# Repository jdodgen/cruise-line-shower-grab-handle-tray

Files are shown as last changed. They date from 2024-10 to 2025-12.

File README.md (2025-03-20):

# Shower grab handle tray
This is a [openSCAD](https://openscad.org/) design to create an accessory that attaches to the grab handle in the cruise ship shower.

The tray stores things normally on the floor and it also has a loop to hang a razor.   
There are scad "lists" for mount and tray versions. 

All/most variables are global and should be easy to customize. 

There are two scad files one for generating [tray](src/universal_tray.scad)s the other for the [mount](src/universal_mounts.scad) part. 
They are interconnected with a shared [dovetail](src/dovetail.scad). 

### current mount stl files
#### [20mm](/src/stl/20mm_mount.stl) grab handle
As found on Grand Princess and Discovery Princess   
I expect it is a pretty standard grab handle.
####  [25x50mm](/src/stl/25mm_mount.stl) shower handle pole 
As found on Discovery Princess 
#### [25mm](/src/stl/25mm_mount.stl) grab handle
not found on cruise ships yet but sort of standard.
#### [32.5mm](/src/stl/32mm_mount.stl) curved shower handle pole
as found on Discovery Princess wheelchair cabins
#### easy to customize
and add other mounts as they are measured

### current tray versions
#### [soap dish](src/stl/tray_short.stl)
ridges to help soap dry
#### [small holder](/src/stl/tray_small.stl)
Holds small/travel bottles of products
#### [large holder](/src/stl/tray_large.stl)
This needes a large printer
#### modular trays [small](src/stl/tray_shortmount.stl) [soap](rc/stl/tray_soapmount.stl) [loop](src/stl/tray_loop.stl)
That can be plugged together multiple ways

#### also easy to add other sizes

## Prototype history/log
first version test.        
A single part.
This was for the curved handle found on all the ships so far. I had to guess on the diameter and made it too big so it was rather sloppy and I had to heat it up to make it work. Learned that it was 20mm not ~1 inch.

second version test.     
New 20mm mount that worked but too fat and tall. needs to be smaller. 
The razor loop needs to be enlarged.

third version test.      
Still a single part.
Version fits nice. A little leaning due to "curve" elongating the lower clamp.
This ship has more places for storage and the shower is on a 25mm pole on a 50mm pole.

forth version test. 
now connecting mounts to trays with a dovetail
two mounts: 20mm and 25x50mm. two trays a "small" and a "soap"   
mount 20mm with "soap" tray   
mount 25x50mm with "small" tray   
All worked fine noticed that trays could be adjusted about 2 degrees up they would level out. Soap dish worked fine but needs ribs for drying.

fifth version test.   
"Tee" post test. the first cabin was assisted care with a different bathroom. It needed a 25mm curved mount.Second cabin tested the "Tee" post mount. It worked ok but a bit large.dovetails need tightening. 

sixth version test.   
Quite saggy, mount needs improvement, also when all is assembled it is a bit too long.  the product tray is too narrow and should be made shorter and wider.  Soap dish needs loops on the sides.

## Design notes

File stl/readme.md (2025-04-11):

## current stl files

Version 7 uploaded 10-apr-2025

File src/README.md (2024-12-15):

# openSCAD and stl source for a add-on tray for cruise line showers

Two scad files, the mounts and the trays.  

currently mounts for:
20mm virtical "grab bars" both grand and royal class ships
25mm bar teed into 50mm stub that supports shower head mount royal class ships
32.5mm curved base shower head mount (found in weelchair accessable showers) 

customizable trays that use a dovetail mount to attach to various mounts.
standard mounts:
soap tray
short tray
long tray

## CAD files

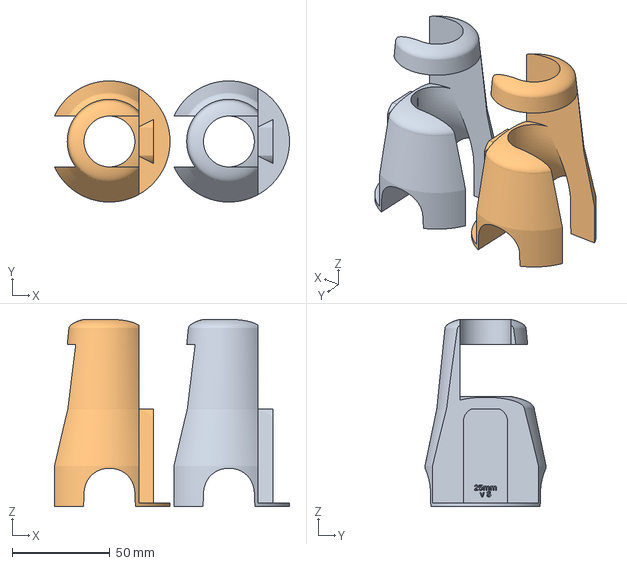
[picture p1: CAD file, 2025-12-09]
src/stl/25mm_mount.3mf
120.3 x 62.0 x 95.9 mm
25mm_mount.stl x 2

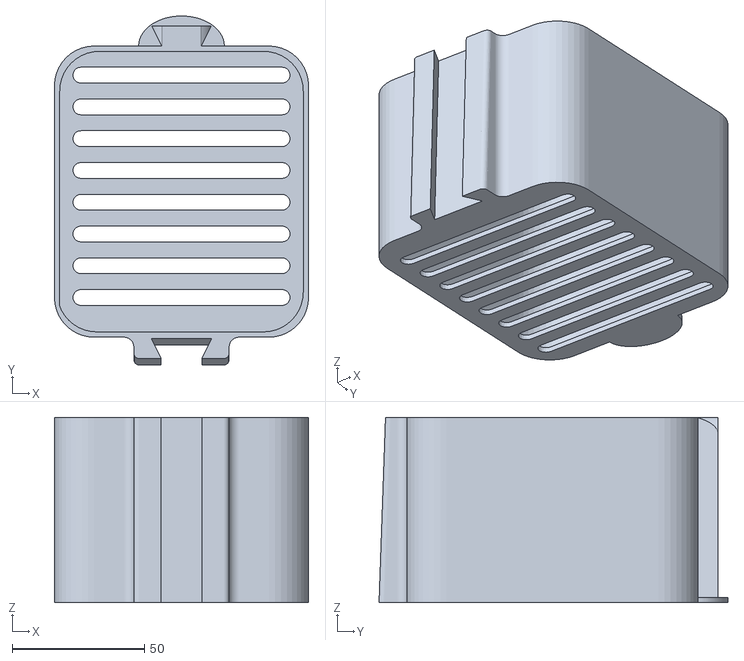
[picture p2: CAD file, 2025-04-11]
stl/short_tray.stl
96.0 x 131.8 x 70.0

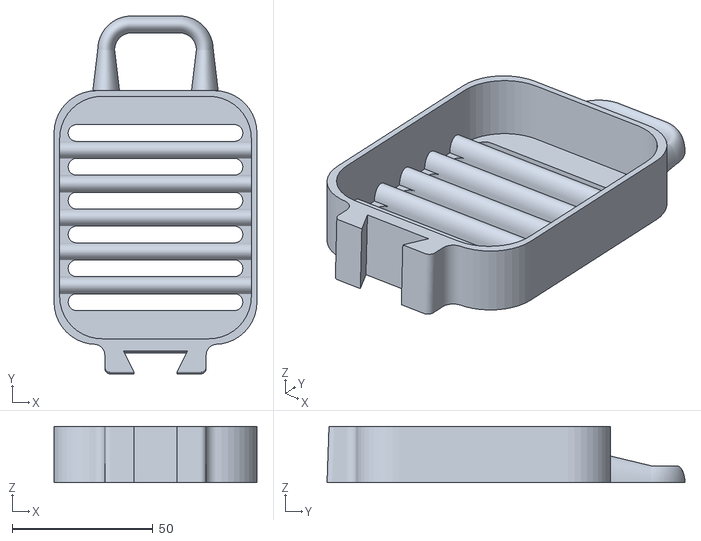
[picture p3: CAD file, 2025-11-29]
src/stl/tray_soap.stl
72.0 x 127.0 x 20.0

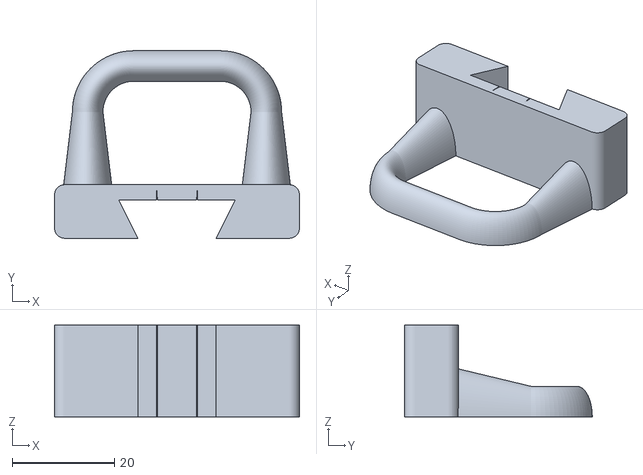
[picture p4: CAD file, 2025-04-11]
stl/loop.stl
48.0 x 36.8 x 18.0

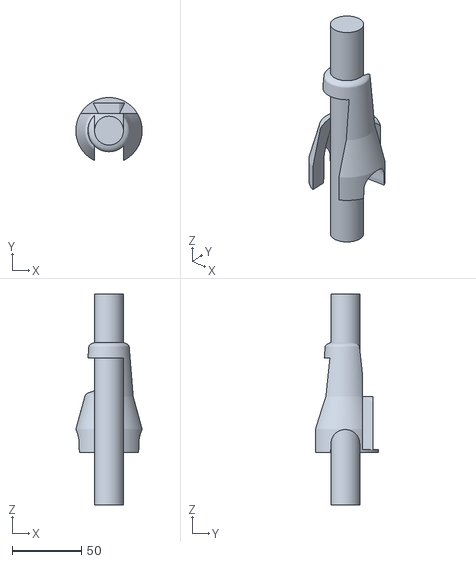
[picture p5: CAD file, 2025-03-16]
src/stl/20mm_mount.stl
47.8 x 45.4 x 152.0

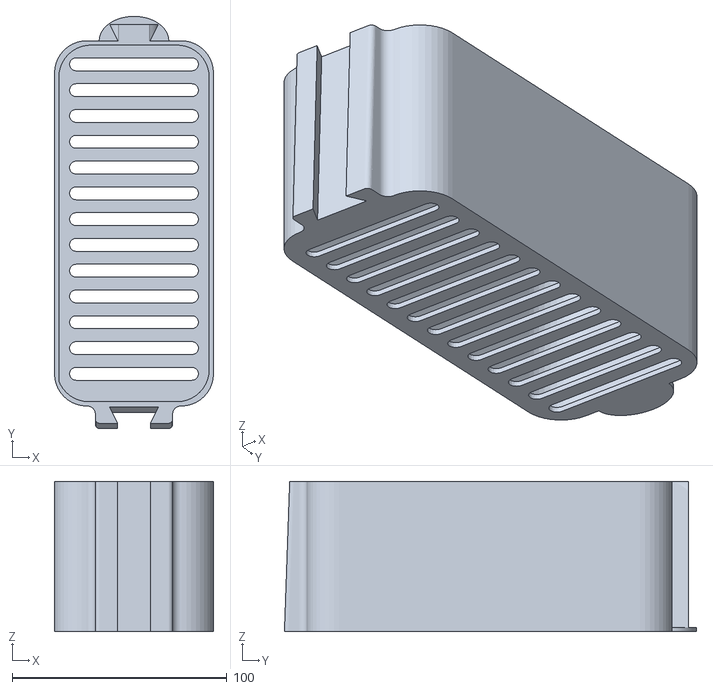
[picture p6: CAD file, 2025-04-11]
stl/170x70mm_long mount.stl
74.0 x 191.8 x 70.0

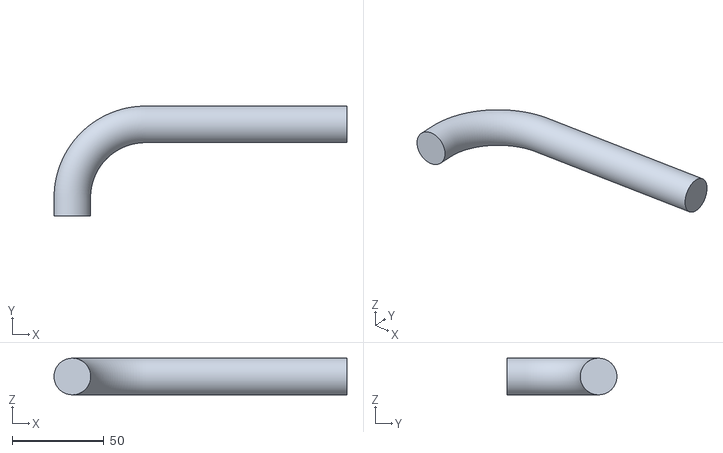
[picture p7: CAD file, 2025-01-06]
src/stl/grand_princess_shower_grab_bar.stl
160.0 x 60.0 x 20.0

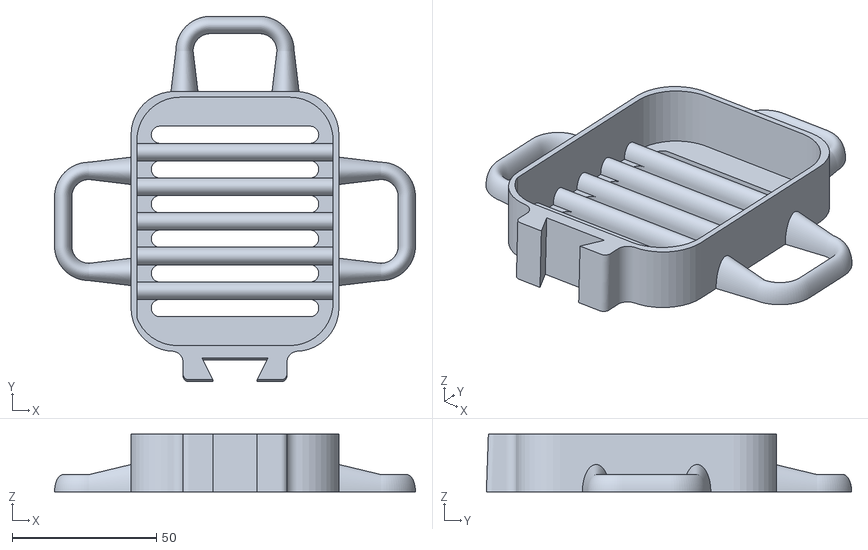
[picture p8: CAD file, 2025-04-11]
stl/soap_tray.stl
125.0 x 126.5 x 20.0

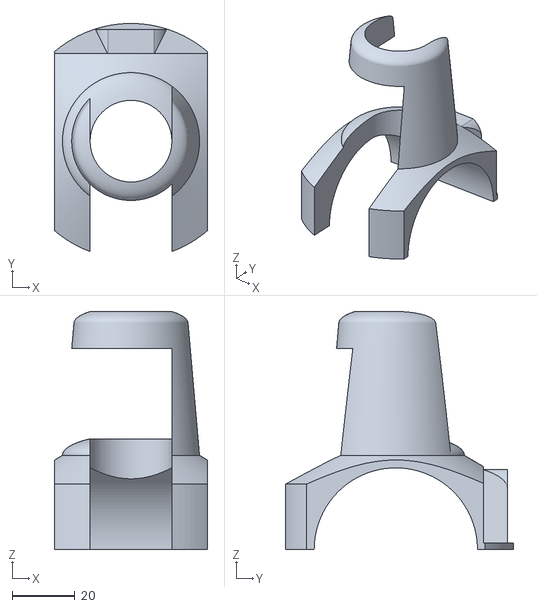
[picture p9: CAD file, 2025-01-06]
src/stl/25x50mm_mount.stl
48.8 x 72.7 x 75.8

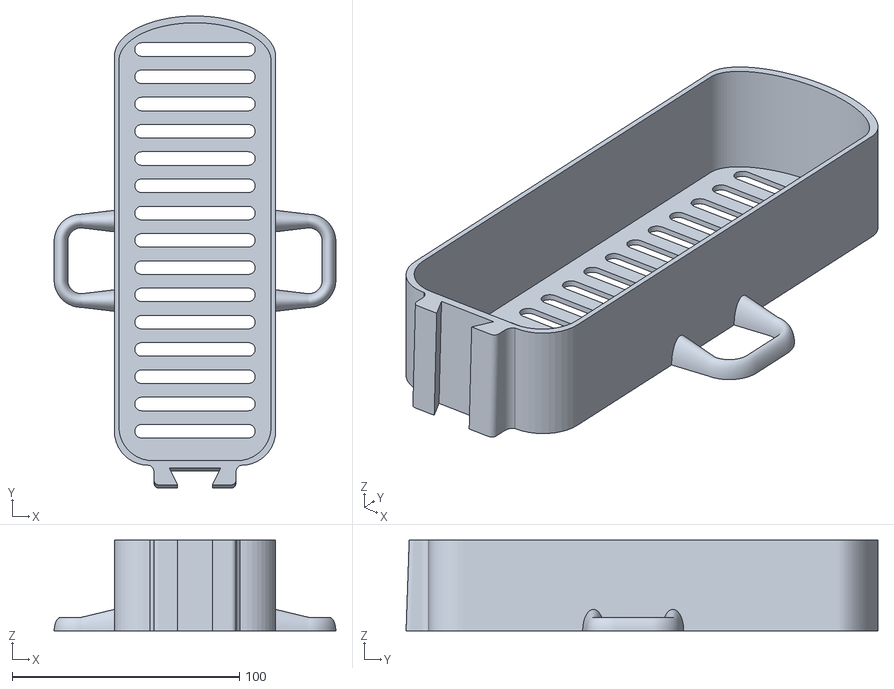
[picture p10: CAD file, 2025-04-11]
stl/long_tray.stl
124.0 x 207.8 x 40.0

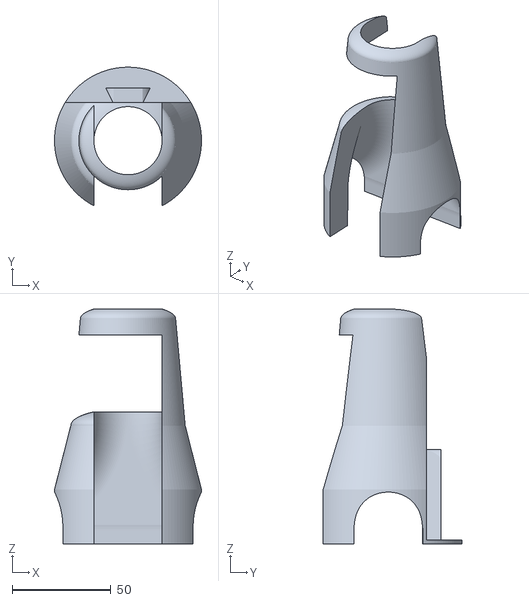
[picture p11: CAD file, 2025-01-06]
src/stl/32mm_mount.stl
74.5 x 70.3 x 119.1

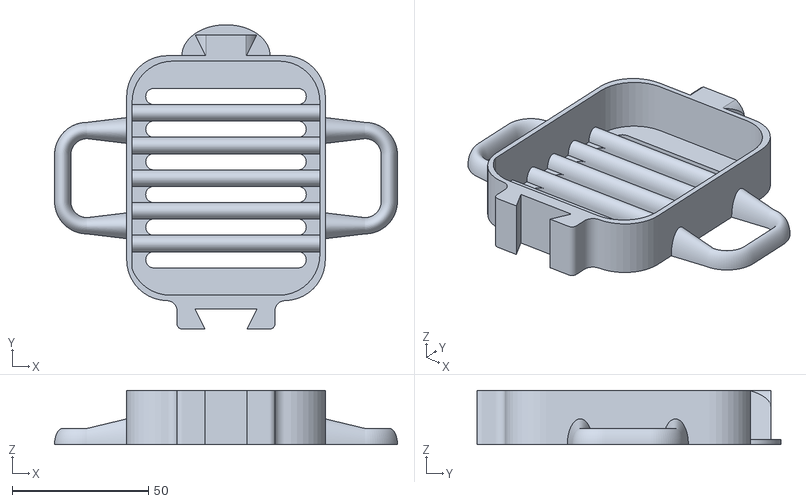
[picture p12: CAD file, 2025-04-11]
stl/soap_mount.stl
126.0 x 111.8 x 20.0

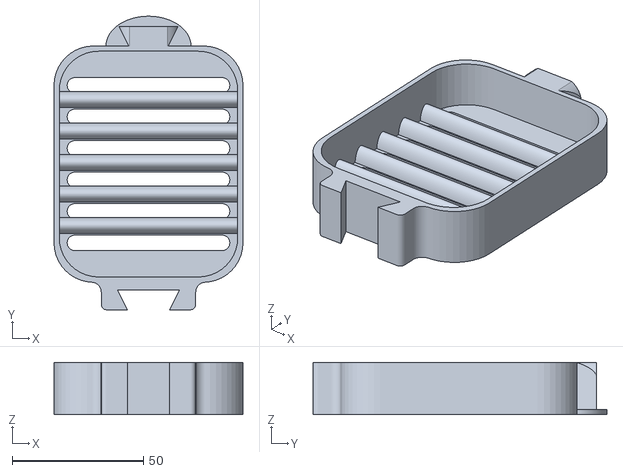
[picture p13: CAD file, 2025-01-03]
src/stl/tray_soapmount.stl
72.0 x 111.8 x 20.0

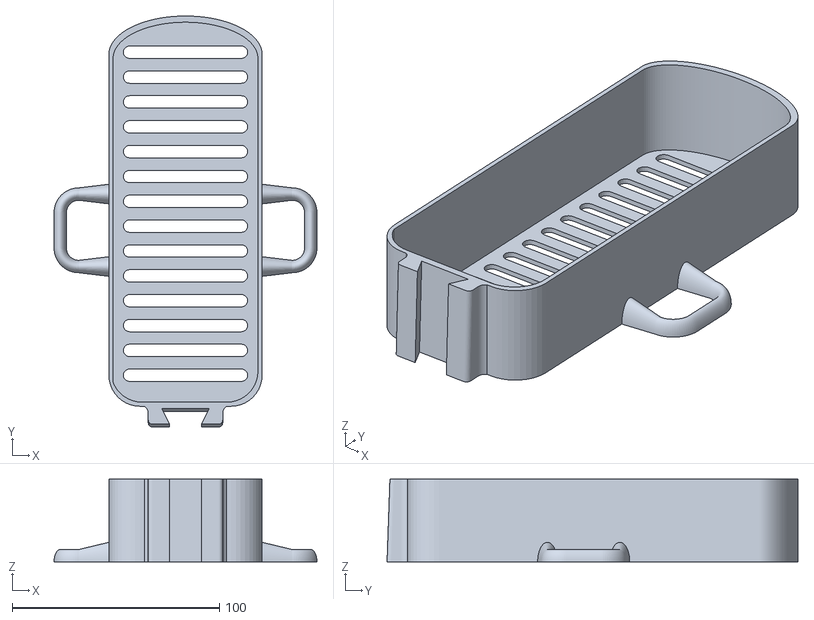
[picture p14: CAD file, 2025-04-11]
stl/170x70mm_long_loop.stl
127.0 x 198.5 x 40.0

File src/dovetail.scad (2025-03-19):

// project dovetail defaults are used. change at risk

default_min_width = 15;
default_max_width = default_min_width*1.5;
default_depth = 15/2;
default_clearance = 0.3;  // was 1 and loose
default_height = 15;

// test examples
dovetail(text="20x50mm",text_title="DIAMETER HHHHHHHHHH"); //height=80);
//translate([0,-5/2,default_height/2])
//        cube([default_max_width*1.5, 5, default_height], center=true);
//translate([0,20,0]) 
//    difference() 
//    {
//        translate([0,default_min_width/2,default_height/2])
//        cube([default_max_width*1.5,
//            default_min_width,default_height], center=true);
//        dovetail(clearance=true);
//    }
// end test
module dovetail(max_width=default_max_width, min_width=default_min_width, 
                depth=default_depth, height=default_height, clearance=false,text=false,text_title=false) {
     clear = clearance ? default_clearance:0;
     d = default_max_width+clear;
     difference()
     { 
         linear_extrude(height=height, convexity=2)
            dovetail_2d(d,
                       min_width + clear,
                        depth);
         translate([0,0,height-6])
            rotate([-90,0,0])
            scale([1,0.7,1])
            difference()
             {
                 d = default_max_width+clear;
                 cylinder(h=default_depth, d=d*2, $fn=120);
                 cylinder(h=default_depth, d=d, $fn=120);
                 translate([0,d,default_depth/2])
                 cube([d*2,d*2,default_depth], center=true);
             }
         if (text) apply_text(text=text, height=height, depth=depth,text_title=text_title);
     }
}
//apply_text();
module apply_text(depth=default_depth, height=default_height, text=false, text_title=false)
{
    letter_height = 1;
    color("red")
    translate([0,depth-(letter_height*0.9), default_height/3])
    rotate([90,0,180])
        linear_extrude(height = letter_height, convexity = 10) 
            text(text, font = "Helvetica:style=Bold", size=3,halign="center" );
    if (text_title) 
        translate([0,depth-(letter_height*0.9), default_height/1.8])
            rotate([90,0,180])
            linear_extrude(height = letter_height, convexity = 10) 
            text(text_title, font = "Helvetica:style=Bold", size=3,halign="center" );  
}

module dovetail_2d(max_width=11, min_width=5, depth=5) {
	angle=atan((max_width/2-min_width/2)/depth);
	echo("angle: ", angle);
	polygon(paths=[[0,1,2,3,0]], points=[[-min_width/2,0], [-max_width/2,depth], 
        [max_width/2, depth], [min_width/2,0]]);
}

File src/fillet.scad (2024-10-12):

module fillet(rot, r, h) {
    //translate([r / 2, r / 2, h/2])
		//rotate([0,0,rot]) 
			difference() {
				//cube([r + 0.01, r + 0.01, h], center = true);
				fillet_cube(rot=rot, r=r, h=h);
				fillet_cylinder(rot=rot, r=r, h=h);
				
				//translate([r/2, r/2, 0])
					//cylinder(r = r, h = h + 1, center = true);
			}
}

module fillet_cube(rot, r, h)
{
	translate([r / 2, r / 2, h/2])
	rotate([0,0,rot]) 
		cube([r + 0.01, r + 0.01, h], center = true);
}

module fillet_cylinder(rot, r, h)
{
	translate([r / 2, r / 2, h/2])
	rotate([0,0,rot]) 
		translate([r/2, r/2, 0])
			cylinder(r = r, h = h + 1, center = true);	
}

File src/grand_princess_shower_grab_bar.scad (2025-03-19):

//   grand princess shower grab bar

postd = 20;
total_height = 150-postd*2;
echo("total bar height",total_height);
from_wall= 40 -(postd/2);
big_plate = 70;
big_plate_thickness = 7;  // measured this but it looks too thick: 15mm;
nut= 32;
outside_bar_to_nut = 40;
nut_thickness = 26; // again measured as 27mm;
bar_to_nut = from_wall-nut_thickness;
echo("calculated bar to nut", bar_to_nut);

function center_bar_to_nut() = outside_bar_to_nut;
echo("measured center_bar_to_nut", center_bar_to_nut());

fudge=0; //-27;
make_top_curve = false;
difference()
{
    translate([0,0,postd/2]) 
    {
        rotate([90,0,90]) bar();
        translate([-postd*2,-50+8,0])
            rotate([90,0,0])
                make_nut(hollow=false);
    }
    translate([-200,-200,-10])
                cube([200,200,10]);  // chop nut for simple printing
}

module make_nut(hollow=true)
{  
    difference(){
      cylinder(d= nut, h=nut_thickness, $fn = 15);
      if (hollow)
        cylinder(d= postd-0.05, h=nut_thickness,
            $fn = 120); 
    }
}
//translate([0,postd,0])bar();
module bar()
{
    
    {
        cylinder(d=postd, h=total_height, $fn = 120);
        color("blue") 
            curve();
        if (make_top_curve == true)
        {
            color("blue") 
                translate([0,0,total_height]) 
                    rotate([180,0,0]) 
                        curve();
        }
    }
}
//mount();
module mount()
{
    difference()
    {
        union()
        {
            cylinder(d= big_plate, h=big_plate_thickness, $fn = 120);
            echo("mount nut_thickness", nut_thickness);
            cylinder(d= nut, h=nut_thickness, $fn = 15);
        }
        cylinder(d=postd, h=total_height, $fn = 120);
    }
        
}

module curve()
{
    {
        //cylinder(d=postd, h=total_height*2); // hole 
        adjust =  0;
        translate([-postd*2.0,0,0])
            rotate([-90,90,0])
                rotate_extrude(convexity = 10,angle=-90, $fn = 120)
                    translate([4*postd/2, 0, 0])
                        circle(r = postd/2,, $fn=120);
       translate([-postd*2,0,-postd*2])
            rotate([-90,90,90])
                cylinder(d=postd, h=from_wall-postd, $fn=120); 
    }   
}

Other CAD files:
src/stl/tray_shortmount.stl
stl/180mm_mount_tray.stl
src/stl/tray_loop.stl
stl/20mm_mount.stl
src/rounded_loop.scad
src/stl/25mm_mount.stl
src/stl/dovetail.stl
src/stl/tray_long.stl
src/stl/tray_short.stl
src/universal_mounts.scad
src/universal_tray.scad
stl/25x50mm_mount.stl

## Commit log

2024-10-23 after cruising with theprototype. Now I have measurements and an improved version
    [single_sided_tray.scad, universal_tray.scad, universal_tray.stl]
2024-10-23 Update universal_tray.scad fixed make_it
    [universal_tray.scad]
2024-12-02 fixed missing function and changed handle to nut
    [grand_princess_shower_grab_bar.scad]
2024-12-03 Test code added
    [rounded_loop.scad, universal_tray.scad]
2024-12-10 fixes and added the "shower head post" version
    [universal_tray.scad]
2024-12-10 fresh stl files
    [bar_soap_holder.stl, shower_soap_holder.stl]
2024-12-15 dovetail connection mount to tray
    [20mm_mount.stl, 25-50mm_mount.stl, tray_short.stl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]
2024-12-15 dovetail code
    [dovetail.scad, dovetail.stl]
2024-12-15 added stl files
    [20mm_mount.stl, 25-50mm_mount.stl, dovetail.stl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]
2024-12-15 cleaned commented code
    [universal_mounts.scad, universal_tray.scad]
2024-12-19 Update universal_mounts.scad with hist of current version data
    [universal_mounts.scad]
2024-12-26 made bottom clamp a part of this_one list. Fixed excess wobble.
    [universal_mounts.scad]
2024-12-26 added ribs, tilt_up and parms in list
    [universal_tray.scad]
2024-12-26 corrected typos in comments
    [universal_tray.scad]
2024-12-26 refreshed the stl files
    [20mm_mount.stl, 25-50mm_mount.stl, 32mm_mount.stl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]
2024-12-26 fixed support base code
    [universal_tray.scad]
2025-01-02 trimmed size and sharp corners
    [universal_mounts.scad]
2025-01-02 current stl files
    [20mm_mount.stl, 25-50mm_mount.stl, 32mm_mount.stl]
2025-01-02 added tilt and ridges
    [universal_tray.scad]
2025-01-03 refreshed stl's
    [25mm_mount.stl, tray_long.stl, tray_loop.stl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]
2025-01-03 added dovetail versions
    [universal_tray.scad]
2025-01-03 refreshed tray stl's
    [tray_long.stl, tray_loop.stl, tray_short.stl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]
2025-01-03 minor edits
    [tray_shortmount.stl, tray_soapmount.stl]
2025-01-03 formatting cleanup
    [universal_mounts.scad]
2025-01-04 reformatted the mount description code
2025-01-06 refresh stl's
    [20mm_mount.stl, 25mm_mount.stl, 25x50mm_mount.stl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]
2025-01-06 added 25mm curved. trim feature to take sharp points off of 25x50mm and future versions
    [dovetail.scad, grand_princess_shower_grab_bar.scad, universal_mounts.scad]
2025-03-09 made 20mm base thicker to reduce wobble
    [universal_mounts.scad]
2025-03-09 starting side mounts and make short tray wider
    [universal_tray.scad]
2025-03-10 added nut
    [grand_princess_shower_grab_bar.scad, universal_mounts.scad]
2025-03-11 added side loops to soap tray
    [universal_tray.scad]
2025-03-16 longer 20mm
    [20mm_mount.stl]
2025-03-18 added 15mm to height, enlarged top for strength, taller dovetail, better stability
    [universal_mounts.scad]
2025-03-18 Tray with tighter dovetail removed support bed
    [dovetail.scad, universal_mounts.scad, universal_tray.scad]
2025-03-19 tightened dovetail saving handle with nut
    [dovetail.scad, grand_princess_shower_grab_bar.scad, universal_tray.scad]
2025-03-19 new long tray
    [universal_tray.scad]
2025-03-19 Dyslexic spelling error
    [universal_tray.scad]
2025-03-20 V7 of mount
    [universal_mounts.scad]
2025-03-28 Shortened long tray
    [universal_tray.scad]
2025-11-29 soap tray improvements
    [tray_soap.stl, universal_tray.scad]
2025-12-09 25mm mount
    [25mm_mount.3mf, universal_mounts.scad]
